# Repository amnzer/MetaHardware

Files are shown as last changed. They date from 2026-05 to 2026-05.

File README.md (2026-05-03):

# MetaHardware
Hardware for MetaSense's KiCad design. 

hardware_v1 is the PCB version used for the prototype mentioned in the final report. 

hardware_v2 aims to fix a few of the major problems that hardware_v1 has in terms of reliability and simplicity, although we have not yet tested hardware_v2. hardware_v2 is the more natural starting point for the next team to pick up the MetaSense project

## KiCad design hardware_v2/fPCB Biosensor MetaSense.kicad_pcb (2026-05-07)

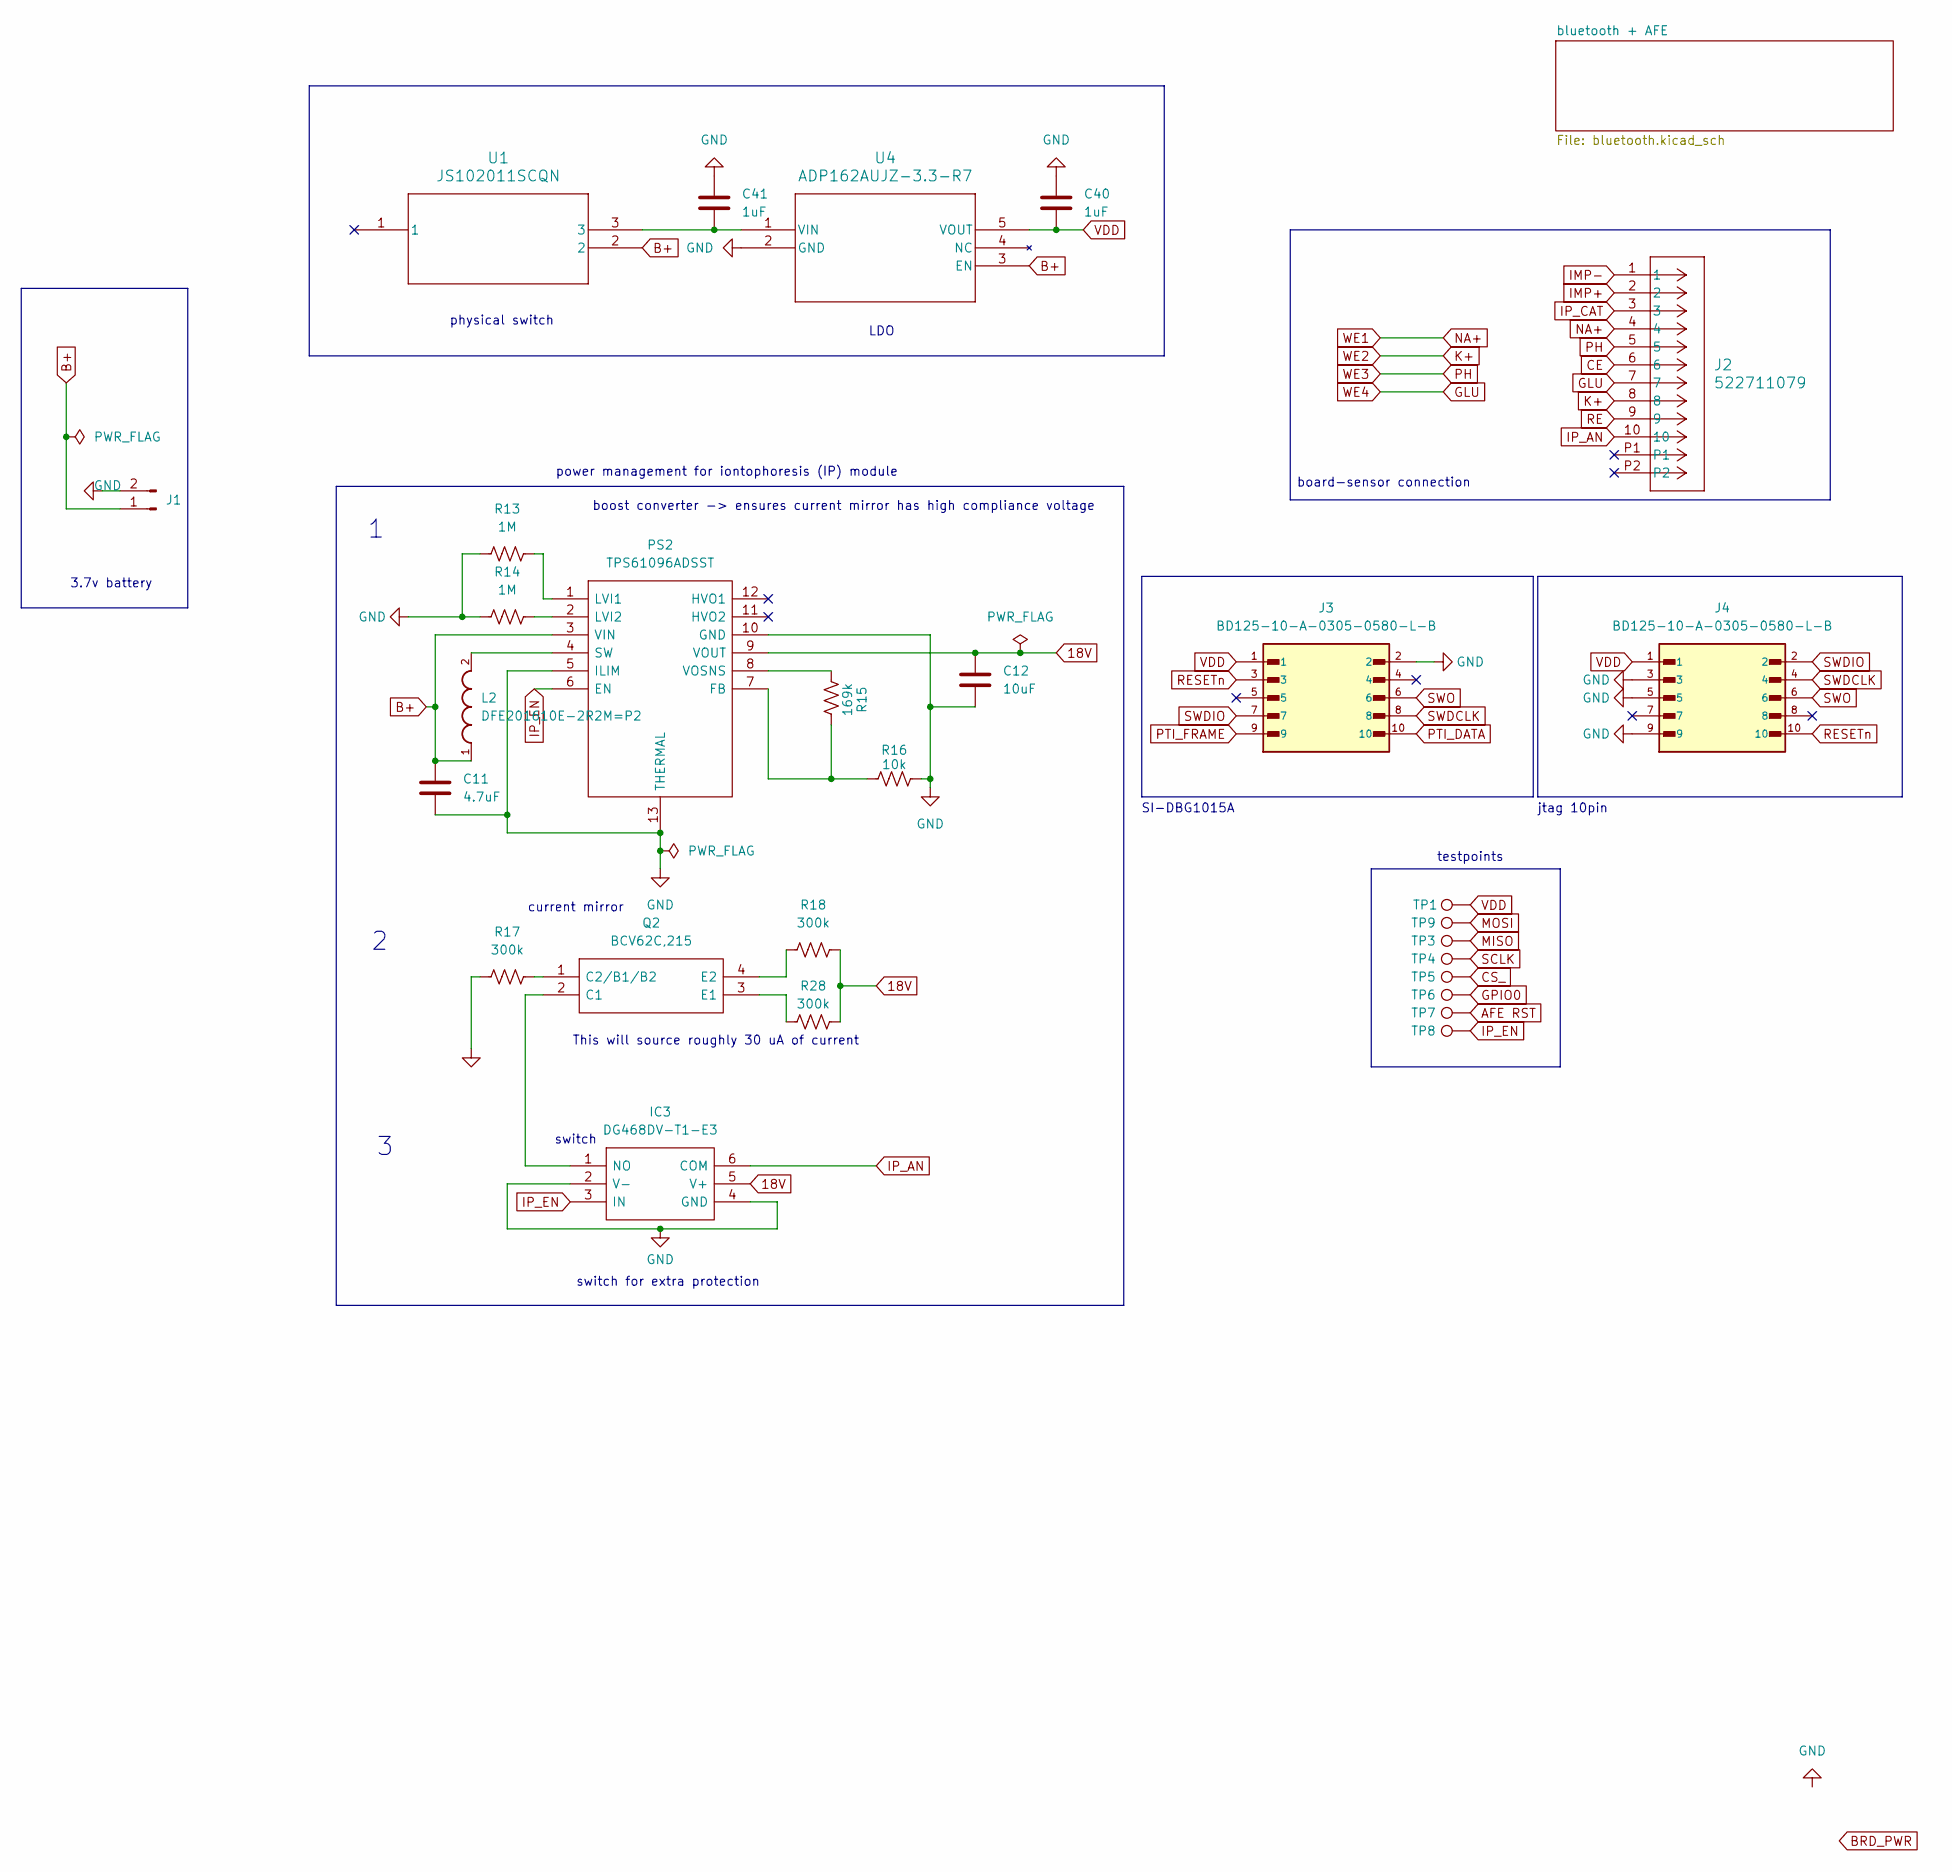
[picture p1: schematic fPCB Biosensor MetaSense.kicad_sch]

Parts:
C11: 4.7uF; C_0603_1608Metric
C12: 10uF; C_1206_3216Metric
C40, C41: 1uF; C_0603_1608Metric
IC3: DG468DV-T1-E3; TSOP6_DG_VIS; Mouser Part Number 781-DG468DV-E3
J1: Conn_01x02_Pin; PinHeader_1x02_P2.54mm_Vertical
J2: 522711079; CON_522711079_MOL
J3, J4: BD125-10-A-0305-0580-L-B; CONN_BD125-10-x-0305-0580-L-x_GCT; PARTREV A
L2: DFE201610E-2R2M=P2
PS2: TPS61096ADSST; DSS0012A; Mouser Part Number 595-TPS61096ADSST
Q2: BCV62C,215; BCV62C215; Mouser Part Number 771-BCV62C-T/R
R13, R14: 1M; R_0603_1608Metric_Pad0.98x0.95mm_HandSolder
R15: 169k; R_0603_1608Metric_Pad0.98x0.95mm_HandSolder
R16: 10k; R_0603_1608Metric_Pad0.98x0.95mm_HandSolder
R17, R18, R28: 300k; R_0603_1608Metric_Pad0.98x0.95mm_HandSolder
TP1, TP3, TP4, TP5, TP6, TP7, TP8, TP9: TestPoint; TestPoint_THTPad_1.5x1.5mm_Drill0.7mm
U1: JS102011SCQN; SWITCH_1SCQN
U4: ADP162AUJZ-3.3-R7

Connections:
18V: C12.1, IC3.5 (V+), PS2.9 (VOUT), R18.2, R28.2; also elsewhere on the board
AFE RST: TP7.1; also elsewhere on the board
B+: C11.1, J1.1, L2.1, PS2.3 (VIN), U1.2, U4.3 (EN); also elsewhere on the board
CE: J2.6; also elsewhere on the board
CS_: TP5.1; also elsewhere on the board
GLU: J2.7; also elsewhere on the board
GND: C11.2, C12.2, C40.2, C41.2, IC3.2 (V-), IC3.4 (GND), J1.2, J3.2, J4.3, J4.5, J4.9, PS2.5 (ILIM), PS2.10 (GND), PS2.13 (THERMAL), PS2.V, R13.1, R14.1, R16.1, R17.1, U4.2 (GND); also elsewhere on the board
IMP+: J2.2; also elsewhere on the board
IMP-: J2.1; also elsewhere on the board
IP_AN: IC3.6 (COM), J2.10
IP_CAT: J2.3; also elsewhere on the board
IP_EN: IC3.3 (IN), PS2.6 (EN), TP8.1; also elsewhere on the board
K+: J2.8; also elsewhere on the board
MISO: TP3.1; also elsewhere on the board
MOSI: TP9.1; also elsewhere on the board
NA+: J2.4; also elsewhere on the board
unnamed: IC3.1 (NO), Q2.2 (C1)
unnamed: PS2.7 (FB), R15.1, R16.2
unnamed: PS2.1 (LVI1), R13.2
unnamed: PS2.2 (LVI2), R14.2
unnamed: L2.2, PS2.4 (SW)
unnamed: PS2.8 (VOSNS), R15.2
unnamed: Q2.1 (C2/B1/B2), R17.2
unnamed: Q2.3 (E1), R28.1
unnamed: Q2.4 (E2), R18.1
unnamed: C41.1, U1.3, U4.1 (VIN)
PH: J2.5; also elsewhere on the board
PTI_DATA: J3.10; also elsewhere on the board
PTI_FRAME: J3.9; also elsewhere on the board
RE: J2.9; also elsewhere on the board
RESETn: J3.3, J4.10; also elsewhere on the board
SCLK: TP4.1; also elsewhere on the board
SWDCLK: J3.8, J4.4; also elsewhere on the board
SWDIO: J3.7, J4.2; also elsewhere on the board
SWO: J3.6, J4.6; also elsewhere on the board
VDD: C40.1, J3.1, J4.1, TP1.1, U4.5 (VOUT); also elsewhere on the board

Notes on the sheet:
current mirror
power management for iontophoresis (IP) module
LDO
boost converter -> ensures current mirror has high compliance voltage
This will source roughly 30 uA of current
switch
board-sensor connection
switch for extra protection
SI-DBG1015A
jtag 10pin
3.7v battery
physical switch
testpoints

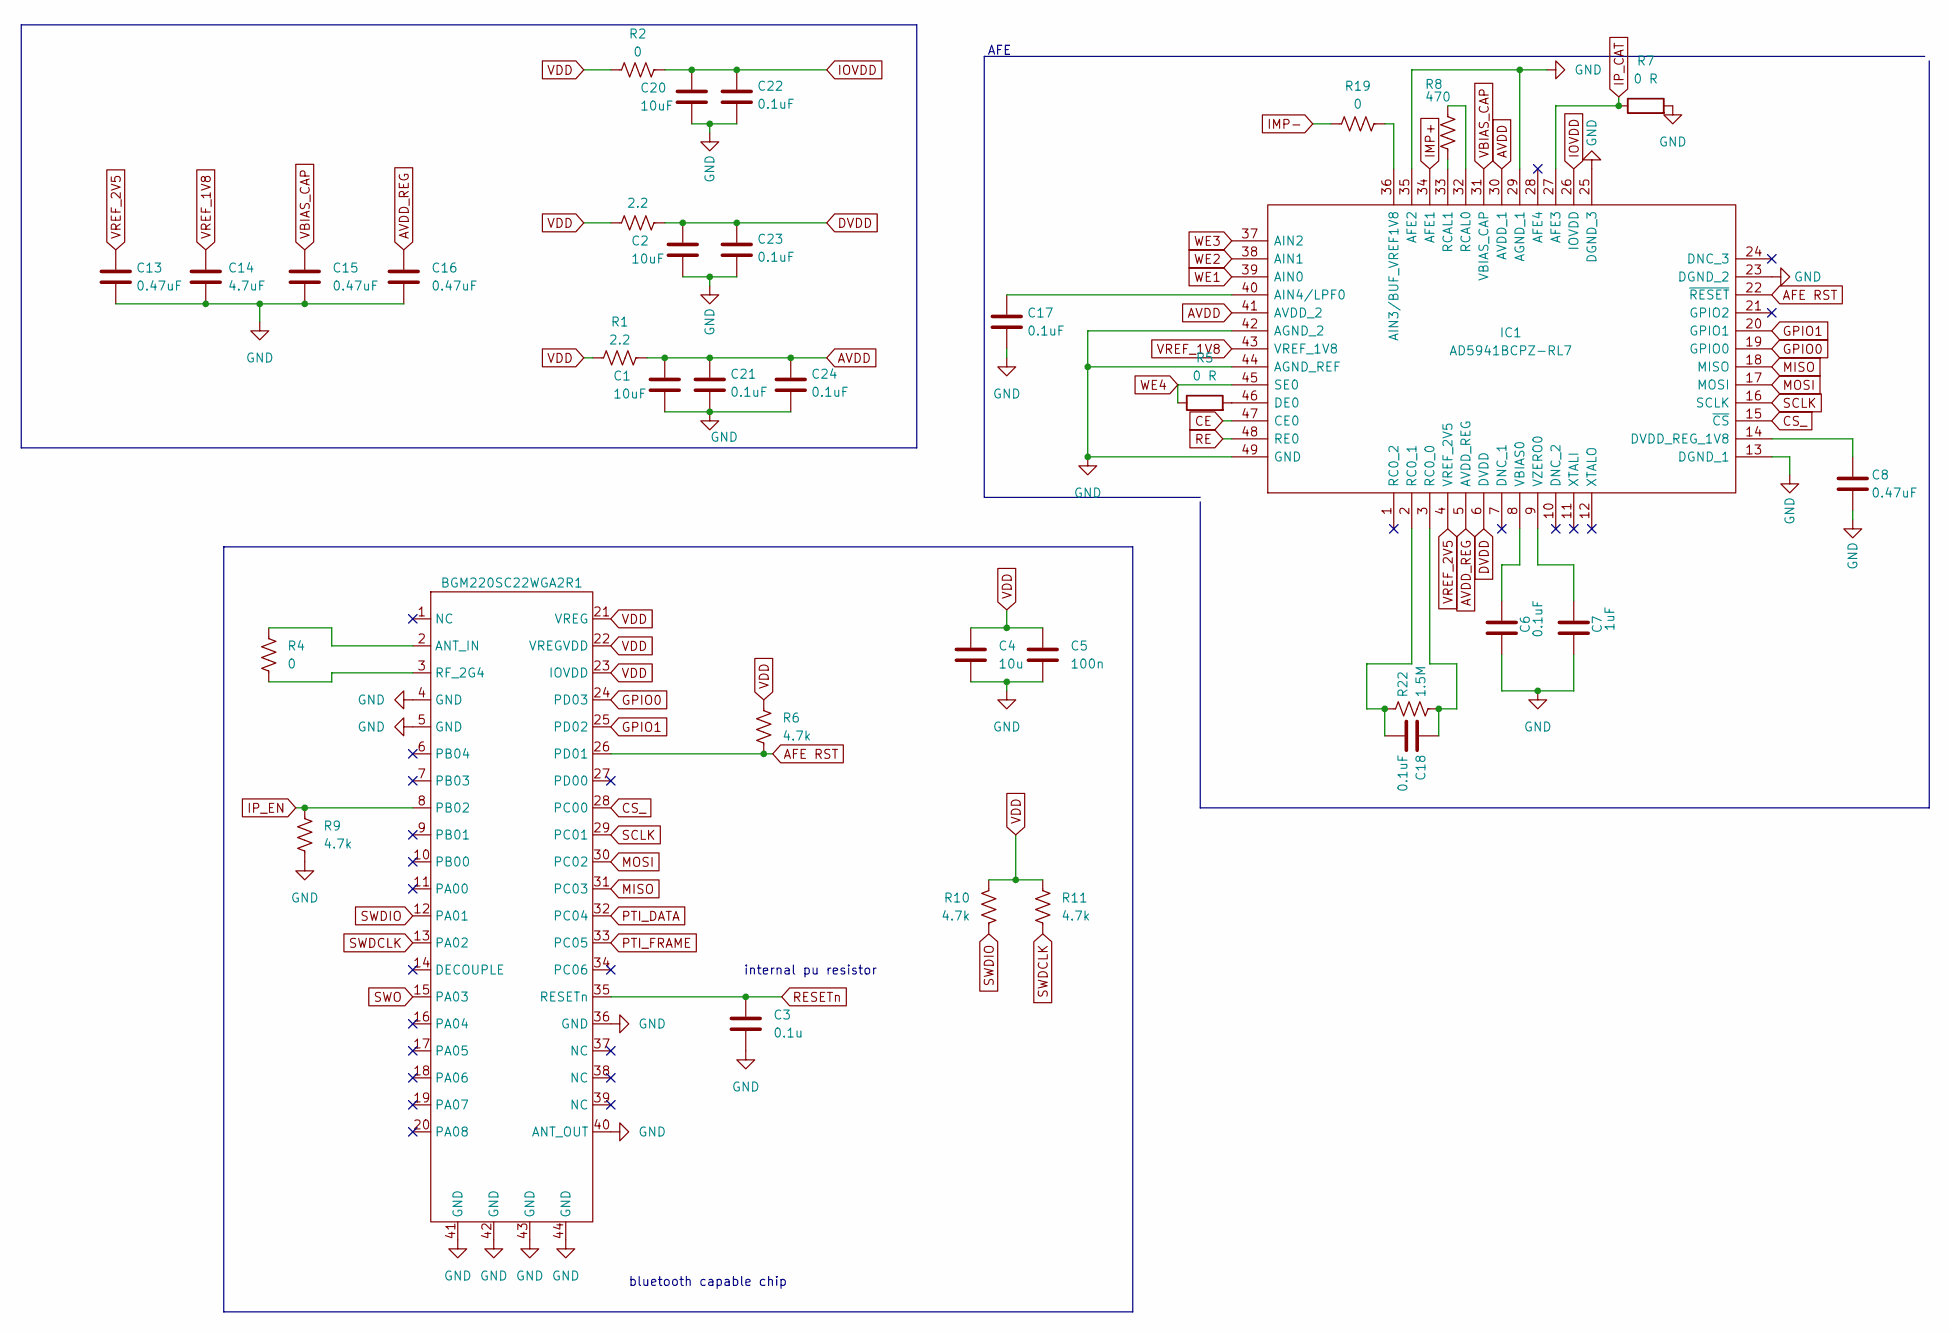
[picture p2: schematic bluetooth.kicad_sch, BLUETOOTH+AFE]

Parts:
BGM220SC22WGA2R1: BGM220SC22WGA2R
C1, C2, C20: 10uF; C_1206_3216Metric
C3: 0.1u; C_0603_1608Metric
C4: 10u; C_0603_1608Metric_Pad1.08x0.95mm_HandSolder
C5: 100n; C_0603_1608Metric_Pad1.08x0.95mm_HandSolder
C6, C17, C18, C21, C22, C23, C24: 0.1uF; C_0603_1608Metric
C7: 1uF; C_0603_1608Metric
C8, C13, C15, C16: 0.47uF; C_0603_1608Metric
C14: 4.7uF; C_0603_1608Metric
IC1: AD5941BCPZ-RL7; QFN50P700X700X80-49N; Mouser Part Number 584-AD5941BCPZ-RL7
R1, R3: 2.2; R_0603_1608Metric_Pad0.98x0.95mm_HandSolder
R2, R19: 0; R_0603_1608Metric_Pad0.98x0.95mm_HandSolder
R4: 0; RES_ERJ1G_PAN
R5, R7: 0 R; R_0603_1608Metric_Pad0.98x0.95mm_HandSolder
R6, R9, R10, R11: 4.7k; R_0603_1608Metric
R8: 470; R_0603_1608Metric_Pad0.98x0.95mm_HandSolder
R22: 1.5M; R_0603_1608Metric_Pad0.98x0.95mm_HandSolder

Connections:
AFE RST: BGM220SC22WGA2R1.26 (PD01), IC1.22 (~RESET), R6.2; also elsewhere on the board
AVDD: C1.1, C21.1, C24.1, IC1.30 (AVDD_1), IC1.41 (AVDD_2), R1.2
AVDD_REG: C16.1, IC1.5 (AVDD_REG)
CE: IC1.47 (CE0); also elsewhere on the board
CS_: BGM220SC22WGA2R1.28 (PC00), IC1.15 (~CS); also elsewhere on the board
DVDD: C2.1, C23.1, IC1.6 (DVDD), R3.2
GLU: IC1.45 (SE0), R5.1; also elsewhere on the board
GND: BGM220SC22WGA2R1.4 (GND), BGM220SC22WGA2R1.5 (GND), BGM220SC22WGA2R1.36 (GND), BGM220SC22WGA2R1.40 (ANT_OUT), BGM220SC22WGA2R1.41 (GND), BGM220SC22WGA2R1.42 (GND), BGM220SC22WGA2R1.43 (GND), BGM220SC22WGA2R1.44 (GND), C1.2, C2.2, C3.2, C4.2, C5.2, C6.1, C7.1, C8.2, C13.2, C14.2, C15.2, C16.2, C17.2, C20.2, C21.2, C22.2, C23.2, C24.2, IC1.13 (DGND_1), IC1.23 (DGND_2), IC1.25 (DGND_3), IC1.29 (AGND_1), IC1.35 (AFE2), IC1.42 (AGND_2), IC1.44 (AGND_REF), IC1.49 (GND), R7.2, R9.2; also elsewhere on the board
GPIO0: BGM220SC22WGA2R1.24 (PD03), IC1.19 (GPIO0)
GPIO1: BGM220SC22WGA2R1.25 (PD02), IC1.20 (GPIO1)
IMP+: IC1.34 (AFE1); also elsewhere on the board
IMP-: R19.1; also elsewhere on the board
IOVDD: C20.1, C22.1, IC1.26 (IOVDD), R2.2
IP_CAT: IC1.27 (AFE3), R7.1; also elsewhere on the board
IP_EN: BGM220SC22WGA2R1.8 (PB02), R9.1; also elsewhere on the board
K+: IC1.38 (AIN1); also elsewhere on the board
MISO: BGM220SC22WGA2R1.31 (PC03), IC1.18 (MISO); also elsewhere on the board
MOSI: BGM220SC22WGA2R1.30 (PC02), IC1.17 (MOSI); also elsewhere on the board
NA+: IC1.39 (AIN0); also elsewhere on the board
unnamed: BGM220SC22WGA2R1.2 (ANT_IN), R4.1
unnamed: BGM220SC22WGA2R1.3 (RF_2G4), R4.2
unnamed: IC1.36 (AIN3/BUF_VREF1V8), R19.2
unnamed: C17.1, IC1.40 (AIN4/LPF0)
unnamed: IC1.46 (DE0), R5.2
unnamed: C8.1, IC1.14 (DVDD_REG_1V8)
unnamed: C18.1, IC1.3 (RC0_0), R22.2
unnamed: C18.2, IC1.2 (RC0_1), R22.1
unnamed: IC1.32 (RCAL0), R8.1
unnamed: IC1.33 (RCAL1), R8.2
unnamed: C6.2, IC1.8 (VBIAS0)
unnamed: C7.2, IC1.9 (VZERO0)
PH: IC1.37 (AIN2); also elsewhere on the board
PTI_DATA: BGM220SC22WGA2R1.32 (PC04); also elsewhere on the board
PTI_FRAME: BGM220SC22WGA2R1.33 (PC05); also elsewhere on the board
RE: IC1.48 (RE0); also elsewhere on the board
RESETn: BGM220SC22WGA2R1.35 (RESETn), C3.1; also elsewhere on the board
SCLK: BGM220SC22WGA2R1.29 (PC01), IC1.16 (SCLK); also elsewhere on the board
SWDCLK: BGM220SC22WGA2R1.13 (PA02), R11.2; also elsewhere on the board
SWDIO: BGM220SC22WGA2R1.12 (PA01), R10.2; also elsewhere on the board
SWO: BGM220SC22WGA2R1.15 (PA03); also elsewhere on the board
VBIAS_CAP: C15.1, IC1.31 (VBIAS_CAP)
VDD: BGM220SC22WGA2R1.21 (VREG), BGM220SC22WGA2R1.22 (VREGVDD), BGM220SC22WGA2R1.23 (IOVDD), C4.1, C5.1, R1.1, R2.1, R3.1, R6.1, R10.1, R11.1; also elsewhere on the board
VREF_1V8: C14.1, IC1.43 (VREF_1V8)
VREF_2V5: C13.1, IC1.4 (VREF_2V5)

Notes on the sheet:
AFE
internal pu resistor
bluetooth capable chip

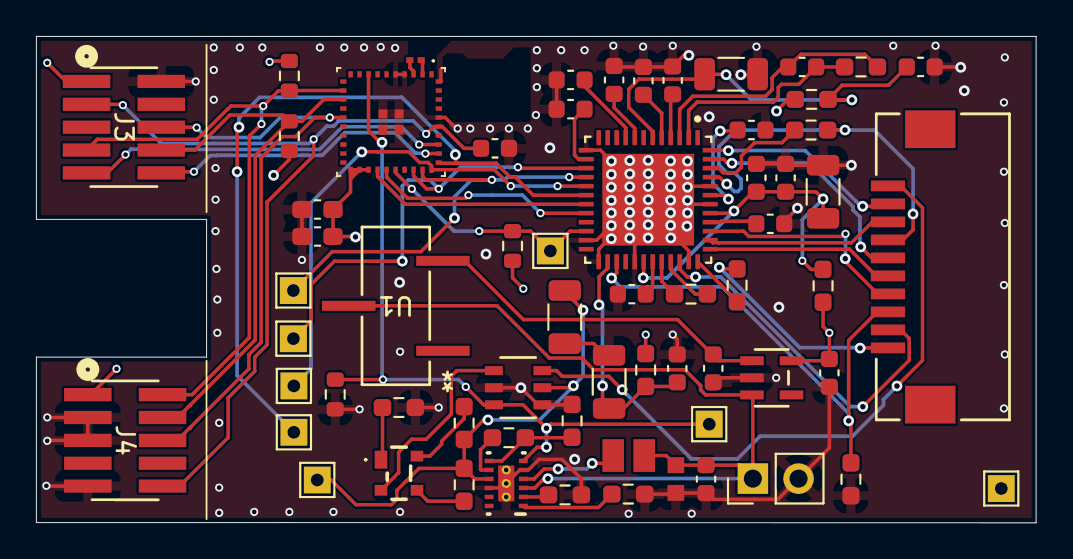
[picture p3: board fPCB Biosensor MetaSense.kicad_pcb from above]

Board: 4 copper layers, 55.5 x 27.0 mm, 64 parts (0 on the bottom side), 57 nets.

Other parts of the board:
C37: GRM188R60J106ME47D
TP10: TestPoint; TestPoint_THTPad_1.5x1.5mm_Drill0.7mm

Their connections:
18V: TP10.1; also elsewhere on the board
B+: C37.2; also elsewhere on the board
GND: C37.1; also elsewhere on the board
